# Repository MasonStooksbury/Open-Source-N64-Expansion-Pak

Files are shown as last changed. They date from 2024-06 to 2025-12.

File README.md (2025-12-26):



# Open Source N64 Expansion Pak | KiCad 9.0

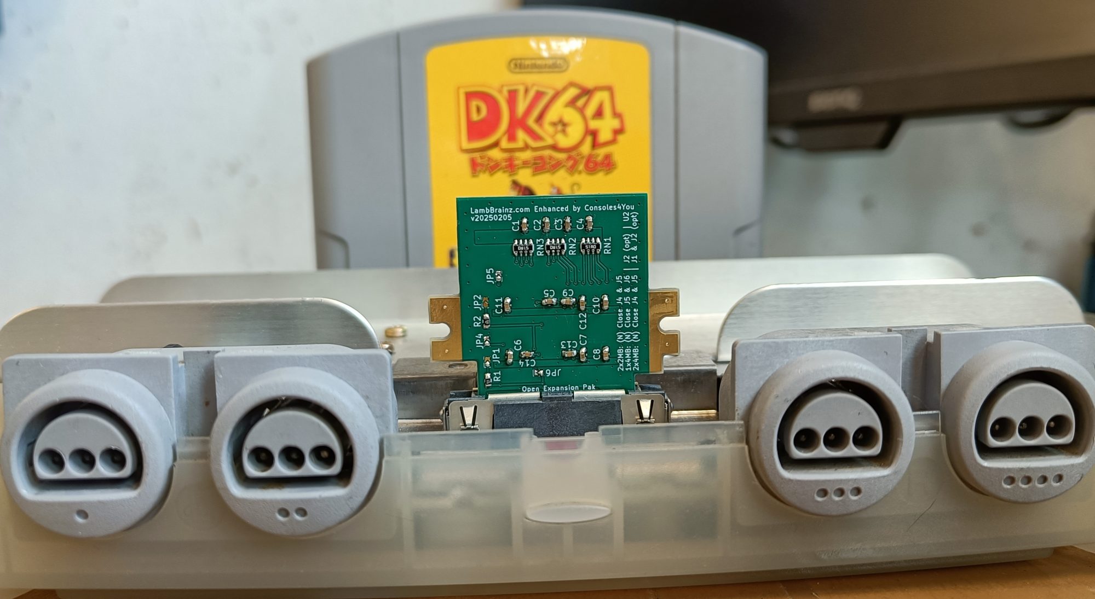
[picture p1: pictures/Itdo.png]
A picture of the custom Open-Source Expansion Pak running


Here are all the files you need to create your own Expansion Pak! All you need to do is clone this repo, open the .kicad_pro file in KiCad, and you can poke around the files.

Fabrication can be done at JLCPCB, production files can be found under releases

<br><br>

# Changelog

- License change from CERN-OHL-P-2.0 and MIT to Attribution-NonCommercial-ShareAlike (CC BY-NC-SA 4.0) (No commercial use of this version is allowed.)
- The only approved, commercial retailers are currently: [consoles4you.ch](https://consoles4you.ch/en/open-expansion-pak) and [classicgamestore.ch](https://classicgamestore.ch/open-expansion-pak)
- Reworked the cart edge connector to be asymetrical, same as the original one
- Cleanup PCB layout
- Swap from single resistors to resistor arrays
- Add jumpers to allow for different configurations
- Reworked the 3D shell design

<br><br>

## Some things to note:

 - In order for this Pak to work you will need two 2MB RAM modules. After lots of digging, the only ones I've found that are available, work, can be found from the US [here](https://dfsales.com/upd488170lg6-a60) and from China [here](https://www.questcomp.com/part/4/upd488170lg6-a60/412376032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)

 - The "ExpansionPak.pretty" folder is a library containing all the footprints needed for the project. Including the Edge Connector footprint created by Bigbass and corrected by Consoles4You (check out more of Bigbass stuff here: [https://hachyderm.io/@bigbass](https://hachyderm.io/@bigbass) and here: [https://github.com/bigbass1997](https://github.com/bigbass1997/)).

<br><br>

# Making your own housing
You can find all the .stl files and instructions on how to print here:
 - [Printables](https://www.printables.com/model/1301125-nintendo-64-open-expansion-pak-shell)

 - The design has a 25x25mm cutout to fit a heatsink. It is recommended to use a tall heatsink made from copper for better heat transmission. Here is a link to a matching one on [Aliexpress](https://s.click.aliexpress.com/e/_ooNrkfH) (affiliate link). If you get this heatsink you can use the file with the grills so that the heatsink is better kept in place.

<br><br>

# Making your own PCB

Navigate to the releases and download the latest release files for JLCPCB.
You can also use the KiCad files to generate production files for any other PCB manufacturer.

## Selecting the correct options in JLCPCB
 - Most of these options will be selected automatically, but be sure to set the ones in the red boxes as they are either structurally required or drastically affect cost
 - `Thickness`: This has to be 1.2 otherwise it will be too thick and you risk over-bending the receiver pins in the N64 
 - `Gold Finger`: By far the most important setting. This tells JLCPCB that we have what is called an `edge connector` (similar to how a RAM stick looks). That way they know to setup all the particular manufacturing stuff that is required to make these
 - `ENIG 2U` or `ENIG 1U`: This is referring to the type of plating we want on our edge connector. We want this to be in gold so that our Exp Pak can survive a few cycles (1U: 50 cycles, 2U 100 cycles) and is less prone to oxidation
 - `Remove product No`: JLCPCB adds a tracking number to the silkscreen of your boards so that their manufacturing process is a little easier. You can select the `Remove Mark` option here at no extra cost to have them not add that. It's not a huge deal, but something to be aware of.

*__NOTE__* - You will have to bevel the edge of cart edge manually as JLCPCB does not do bevelled edges on PCBs smaller than 700mm x 700mm

<br><br>

# PDF Schematic

You can find the schematic as a pdf [here](https://github.com/MasonStooksbury/Open-Source-N64-Expansion-Pak/blob/main/files/oexp.pdf), this might be helpful if you don't use Kicad and want to know more about the jumper settings.

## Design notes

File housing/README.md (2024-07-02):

# Custom, 3D-printable Housing

I've provided 3MF and STEP files for the housing so that it should work with any program and also be editable (should you want to modify it). I'll be the first to admit this may not be the best or most efficient design, but I wanted it to be relatively simple, rugged, mechanically stable, allow me to easily change it for upcoming projects, and not require supports when printing.

1) The design has a 25x25mm cutout to fit a heatsink. The one I have in the picture is 5mm tall, but you could easily fit a 7mm one (maybe an 8mm, but I haven't tested it. Just doing some measurements). At the time of writing, you can purchase these on Amazon [here](https://www.amazon.com/dp/B08HLY7BKR?psc=1&ref=ppx_yo2ov_dt_b_product_details) (not an affiliate link)

1) When printing, you'll want to flip the top section so that the inside is facing upwards. This design also does not require supports when printing. I did sand the inside of mine a little for a tighter fit, but this shouldn't be necessary depending on your printer and settings

1) The design is meant to be used with two M2 screws to hold everything together, but you can modify the hole if needed. The screws need to be at least 5mm long and can go up to 8 or 9 I think. I designed this to not use threaded inserts (as a lot of people do not have them), but if you would like to use those, I made the geometry of the holes very simple so that you could modify them to use inserts or some other solution. `NOTE: If you modify the holes in the top of the shell, be sure to fillet the end like I have so that you won't need to use supports`

1) Finally, I left the back face blank instead of putting some annoying logo or something. This way you can design the housing however you like!

<br><br>

Open project

<br>

Open project

<br>

Open project

<br>

Open project

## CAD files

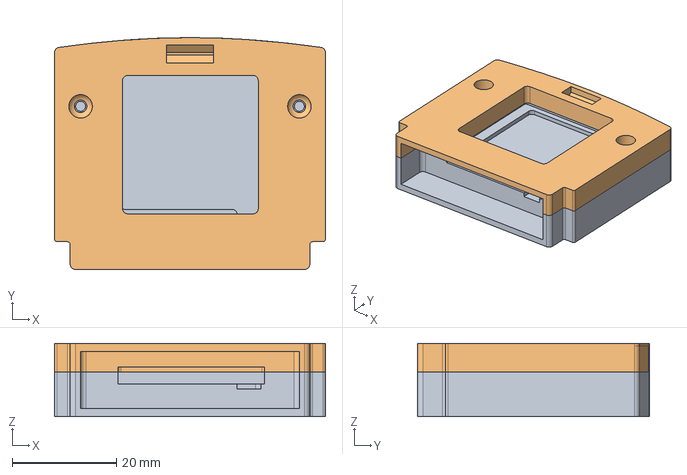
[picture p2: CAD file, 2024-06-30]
housing/Open Source N64 Expansion Pak Shell.step
51.9 x 44.4 x 14.0 mm

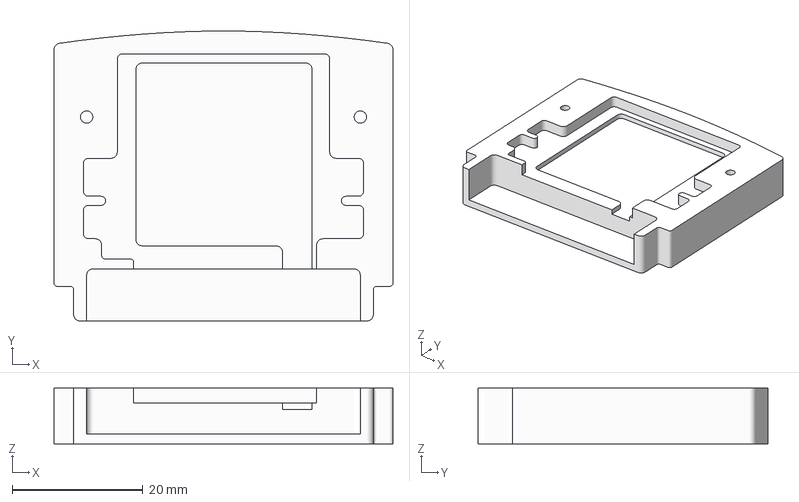
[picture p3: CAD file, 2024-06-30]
housing/Shell Bottom.3mf
51.9 x 44.4 x 8.50 mm

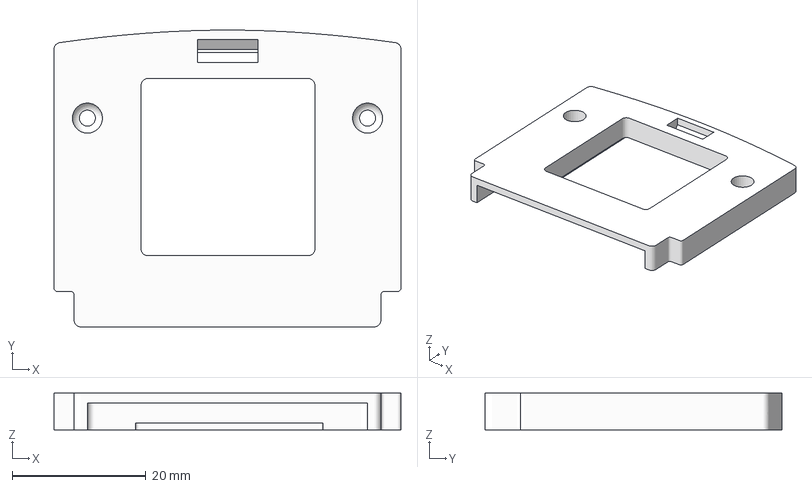
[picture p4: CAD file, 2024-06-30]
housing/Shell Top.3mf
51.9 x 44.4 x 5.50 mm

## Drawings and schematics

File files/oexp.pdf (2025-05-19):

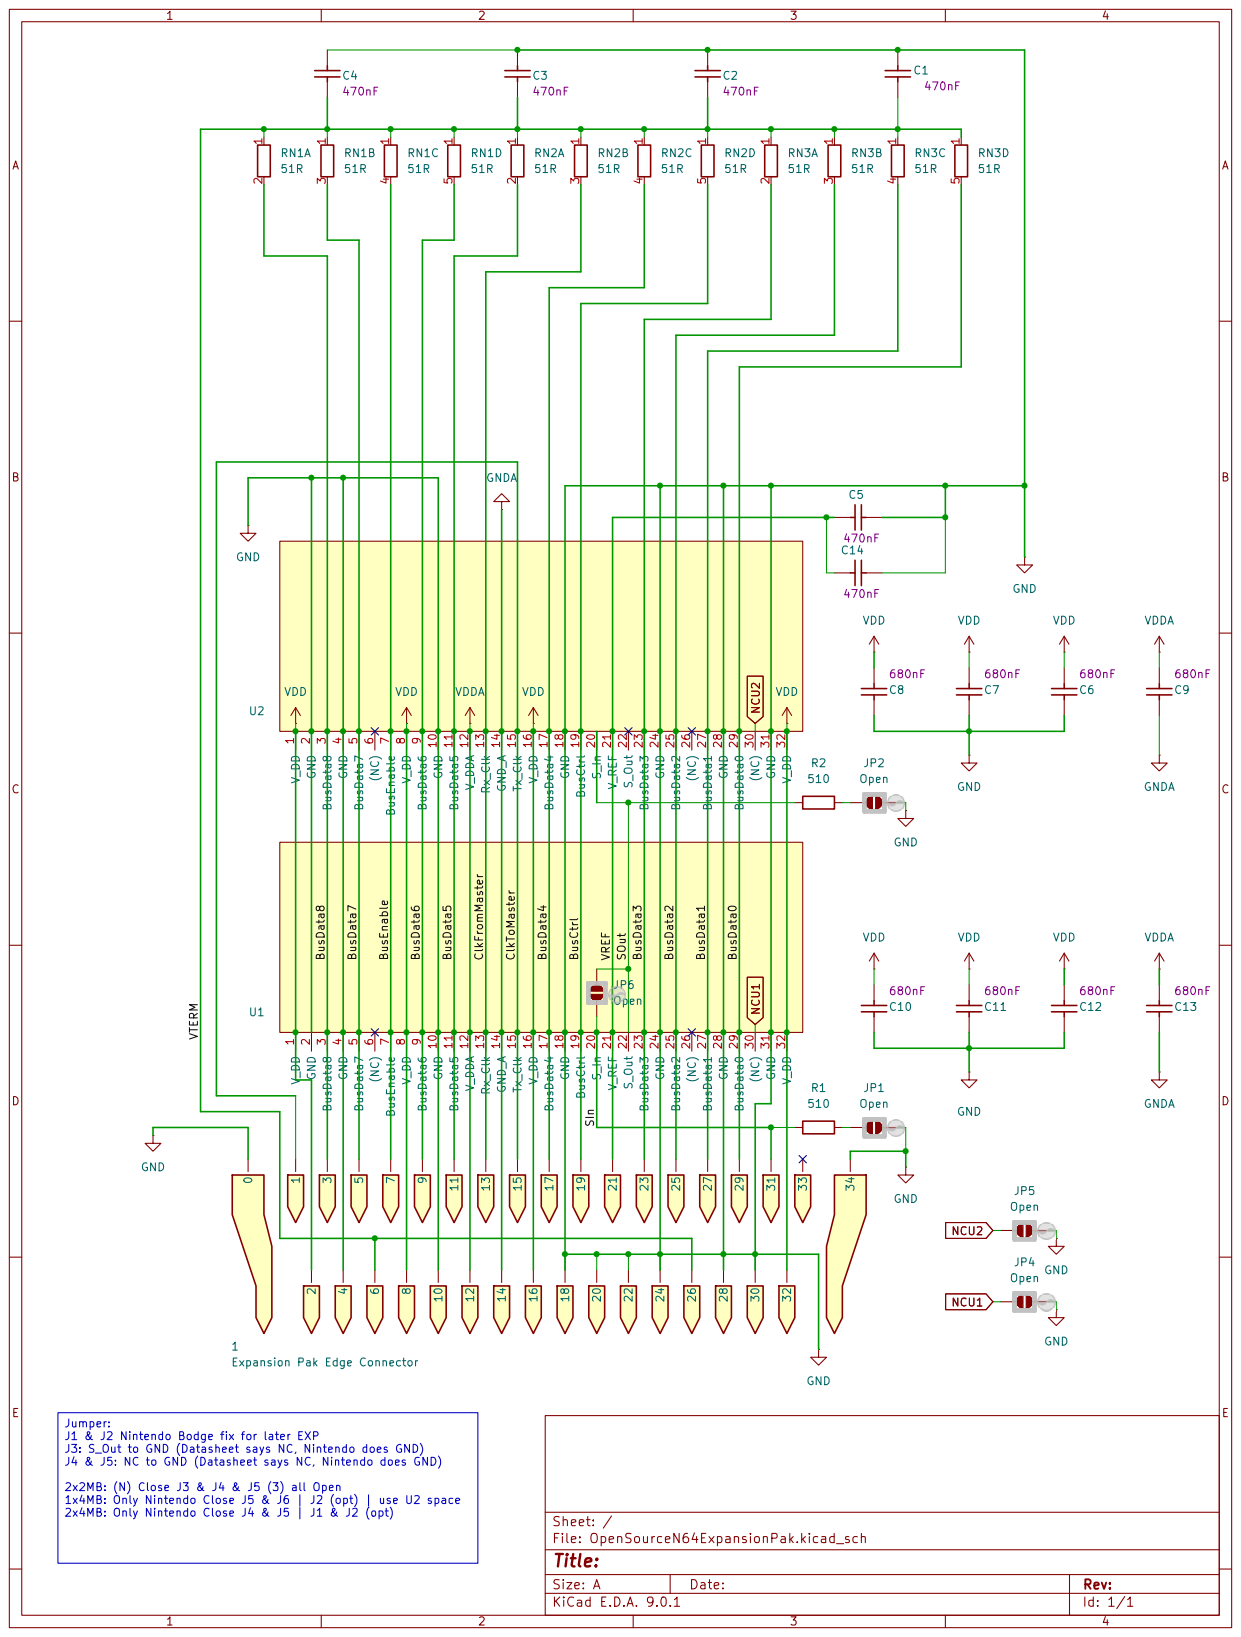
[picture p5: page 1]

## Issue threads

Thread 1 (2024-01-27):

Question about Sin/Sout pull down resistor

littlebalup, 2024-01-27:
Hi,
I'm looking to recycle a pair of original 2MB RDRAM18 from a ruined N64 motherboard to make an homemade Expansion Pack for another machine.
This project looks exacltly what I need thanks.
I didn't deep dived into N64 rdram / expansion pack / jumper pack architecture yet but I'm already seeing something strange to me on your schematic:
You connected the 510ohm resistor to the S_in line of the U2 chip (which should be connected to the S_out of the last rdram chip of the motherboard via your edge connector pin 31 I guess).
That resistor shouldn't be connected to the U2 S_out / U1 S_in line instead? Or even to the U1 S_out? As I understand, U1 is the last rdram chip of the serie.

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

or

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

I planed to trace Sin / Sout of my motherboard, jumper pack and of an original expansion pack to better understand this. But your thought whould be appreciated too.

MasonStooksbury, 2024-01-27:
Hey, thank you so much for looking into this! I'm currently at a family event but will dive deeper into this when I get home tonight. I'll report back with any findings!

MasonStooksbury, 2024-01-27:
So I couldn't stay away from this and I think you may have caught an issue lol I've been having intermittent and often dangerous consequences with this pak and I wonder if this could be the issue. Once I get home I'll try and create bodge for the board and see if anything changes.

littlebalup, 2024-01-30:
I'm not even sure that R13 resistor is necessary. I'm not seeing it on official NUS-RMC-10 expansion pak board or on jumper pak. Where does it come from?

MasonStooksbury, 2024-01-30:
It's not on early versions, you are correct. However, they added it in later versions (my best guess is for stability since RDRAM is incredibly finicky when it comes to termination resistors and stuff). You can find a more detailed write up I made over on Reddit. I think it's the last point in that update

https://www.reddit.com/r/n64/comments/1042myr/open_source_expansion_pak_update_and_help_wanted/

littlebalup, 2024-01-30:
> It's not on early versions, you are correct. However, they added it in later versions (my best guess is for stability since RDRAM is incredibly finicky when it comes to termination resistors and stuff). You can find a more detailed write up I made over on Reddit. I think it's the last point in that update
>
> https://www.reddit.com/r/n64/comments/1042myr/open_source_expansion_pak_update_and_help_wanted/

Got it. Interesting. Do you have an idea of that board revision? NUS-RMC-##?

https://photos.google.com/share/AF1QipO4aWchxXKLJYNMali1IsJKWliu4HdxEcPb6OW7lAtu6cvlLj7B-13hjv64Gd0HzA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

MasonStooksbury, 2024-01-30:
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

I'll do you one better! Here's a spreadsheet where I kept track of everything I could find (along with what people submitted)

https://docs.google.com/spreadsheets/d/1Ax2_HSiqV_8NazG6FtHj_OeQ6TdKuoSON_qMUd4TySQ/edit?usp=sharing

littlebalup, 2024-01-30:
I'll definitely open one of mine to check tonight. I'll also look at the motherboard RDRAM chips, specially the associated decoupling caps and pull-up/down resistors if any.
Meanwhile I reversed engineered the Jumper pak to better understand the basic RDRAM bus termination. Here are my schematics if needed for future reference.
https://www.dropbox.com/scl/fi/4soicun3c8norochmqen7/Jumper-Pak-NUS-RTC-03.pdf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
https://www.dropbox.com/scl/fi/8s8tj27t9gtrvfqb0hmch/Jumper-Pak-NUS-RTC-10.pdf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

ArtFellResist, 2024-02-22:
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

Idk if you already seen this, but I've found this forum where this user posted a lot of different "Expansion Pack"s, both sides

https://bitbuilt.net/forums/index.php?threads/n64-expansion-paks-ram-part-numbers.3943/

Closed 2024-05-21.

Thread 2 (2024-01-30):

C1 Not Connected to Ground

Arthrimus, 2024-01-30:
Hello, I was looking over your PCB file and noticed that C1 does not connect to the ground pour. In the schematic it is connected, just not on the board file. I corrected it on my end, as well as added an extra row of 1.8uf capacitors closer to the second ram chip. I added a few of these to my most recent PCB order and so far my testing has shown it to be stable with these modifications, but I did see the other issue about the Sin/Sout resistor, so I'm interested to see what comes of that.

MasonStooksbury, 2024-01-30:
No. Freaking. Way... I cannot believe I missed this. I must not have had the nets setup correctly in KiCad so I never got a warning about it.

Thank you so much for catching this, I cannot wait to bodge this and see if it helps the issues I've been having.

MasonStooksbury, 2024-01-30:
Fixed this in [this commit](https://github.com/MasonStooksbury/Open-Source-N64-Expansion-Pak/commit/a4516c25a9957c73ee85d103e183fb76fd3b955a). Thank you so much for catching that and posting an issue.

I also posted another comment regarding that extra resistor. TL;DR, I have no proof that it's necessary other than the fact that Nintendo added it to later revisions of their board. So they must have done some testing and determined it to be important.

I'm gonna go ahead and close this, but please feel free to continue the conversation regarding the resistor over on that issue!

Closed 2024-01-30.

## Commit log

2023-10-01 Adding instructions for creating a board with PCBWay as well as updating the README
2023-10-02 Modifying BOM, cleaning up schematic
    [OpenSourceN64ExpansionPak.csv]
2024-01-30 Fixed C1 not being connected to ground. Thanks, Arthrimus
    [OpenSourceN64ExpansionPak.kicad_pcb]
2024-01-30 Updated back picture of the board
2024-05-27 Potential fix for the N64-killer problem
    [OpenSourceN64ExpansionPak.kicad_pcb, OpenSourceN64ExpansionPak.kicad_sch]
2024-06-15 Fixed the N64-killer issue
    [BOM_PCBWay.xlsx]
2024-06-20 Keyed the board so that it has definitive sides when I make the housing
    [OpenSourceN64ExpansionPak.kicad_pcb]
2024-06-21 Fixed disconnected capacitor issue
    [OpenSourceN64ExpansionPak.kicad_pcb, OpenSourceN64ExpansionPak.kicad_sch]
2024-06-21 Updated schematic with capacitor fix
2024-06-28 Upgrading to KiCad 8.0
    [OpenSourceN64ExpansionPak.kicad_pcb, OpenSourceN64ExpansionPak.kicad_sch]
2024-06-30 Adding shell files
    [BOM_PCBWay.xlsx, Open Source N64 Expansion Pak Shell.step, OpenSourceN64ExpansionPak.csv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]
2025-05-19 Fix N64 Killer and more
    - License change from CERN-OHL-P-2.0 and MIT to Attribution-NonCommercial-ShareAlike (CC BY-NC-SA 4.0) (No commercial use of this version is allowed.)
    - Reworked the cart edge connector to be asymetrical, same as the original one
    - Cleanup PCB layout
    - Swap from single resistors to resistor arrays
    - Add jumpers to allow for different configurations
    - Reworked the 3D shell design
    [BOM_PCBWay.xlsx, OpenSourceN64ExpansionPak.csv, OpenSourceN64ExpansionPak.kicad_pcb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]
2025-05-19 Add pictures and schematic as PDF

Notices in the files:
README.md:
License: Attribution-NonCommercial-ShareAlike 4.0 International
